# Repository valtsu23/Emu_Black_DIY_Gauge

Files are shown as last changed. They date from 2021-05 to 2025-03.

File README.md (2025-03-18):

# Emu_Black_DIY_Gauge
### Adafruit Feather M4 CAN Express with 2.4" TFT FeatherWing displaying sensor values 
### Updated 18.3.2025 and now supports Circuitpython 9 
Project goal was to create a small gauge for my Honda S2000 that displays time and sensor values from car ECU. 
Car is equipped with Ecumaster Emu Black ECU that can send data to CAN bus. Power supply for the device is 12v. 

### Hardware: 
- Adafruit Feather M4 CAN Express with ATSAME51 
- Adafruit 2.4" TFT FeatherWing 
- Adafruit DS3231 Precision RTC Breakout 
- JST-SM 4pin connector
- 5v regulator circuit
  - 7805 regulator
  - 1uF 35v tantalum capacitor
  - Proto board pcb
 
### Case
- Original desing (feather-tft-case): https://www.thingiverse.com/thing:2209964/files
- I removed the hole for the switch and added hole for the connector
- 3d printed from PETG
- 4 x M2.5 Machine Screws

### Cost
- Parts in total about 80€ 
- Case was 20€ printed by a hobbyist

### Display features: 
- 3 different tabs showing different values and the tab can be changed by touching the screen
- Last used tab is saved to SD card and read from there on boot 
- Video of the working display: https://youtu.be/Mr_nFbw4OqU

### Wiring notices
- DS3231 VIN to Feather 3V pin
- Capacitor on input side of the regulator 
- Regulator output connected to USB-pin on Feather (not the recommended way, because it might damage the computer plugged to usb-port)
More info: https://learn.adafruit.com/adafruit-feather-m0-basic-proto/power-management

### Understanding how it works
- The code.py file contains the main code. I have used many examples to build the code.
- Data showed on the diplay is split in several goups. There is one main group and 5 lower groups. Data of the 4 groups is changed during the tab change. 
Check links 1 and 2 about controlling the display. 
- Link 3 helps you undestand the Can-Bus communication. 
- I'm using Struct library to unpack the Can-Bus messages (links 4 and 5)

### Useful links
1. https://learn.adafruit.com/adafruit-2-4-tft-touch-screen-featherwing/2-4-tft-featherwing
2. https://learn.adafruit.com/circuitpython-display-support-using-displayio/library-overview
3. https://learn.adafruit.com/using-canio-circuitpython
4. https://docs.python.org/3/library/struct.html
5. https://en.wikipedia.org/wiki/C_data_types

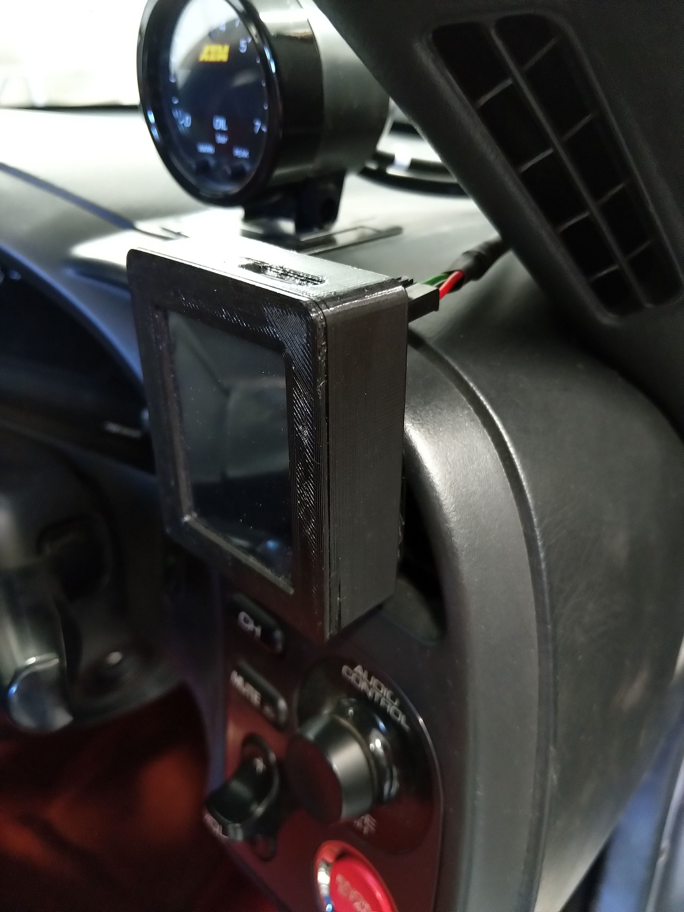
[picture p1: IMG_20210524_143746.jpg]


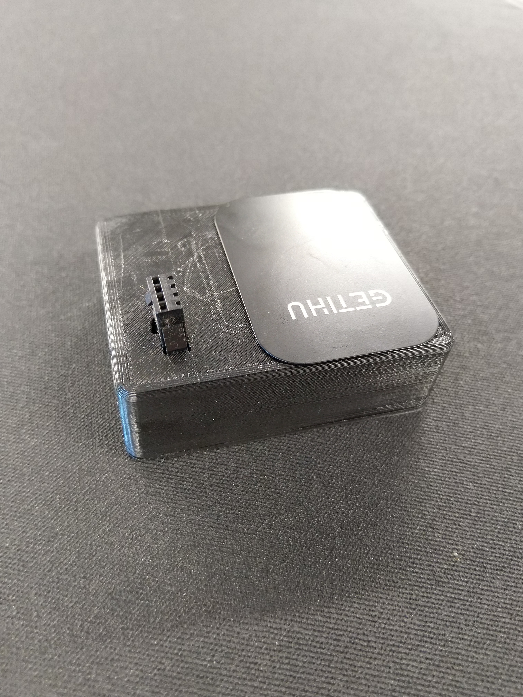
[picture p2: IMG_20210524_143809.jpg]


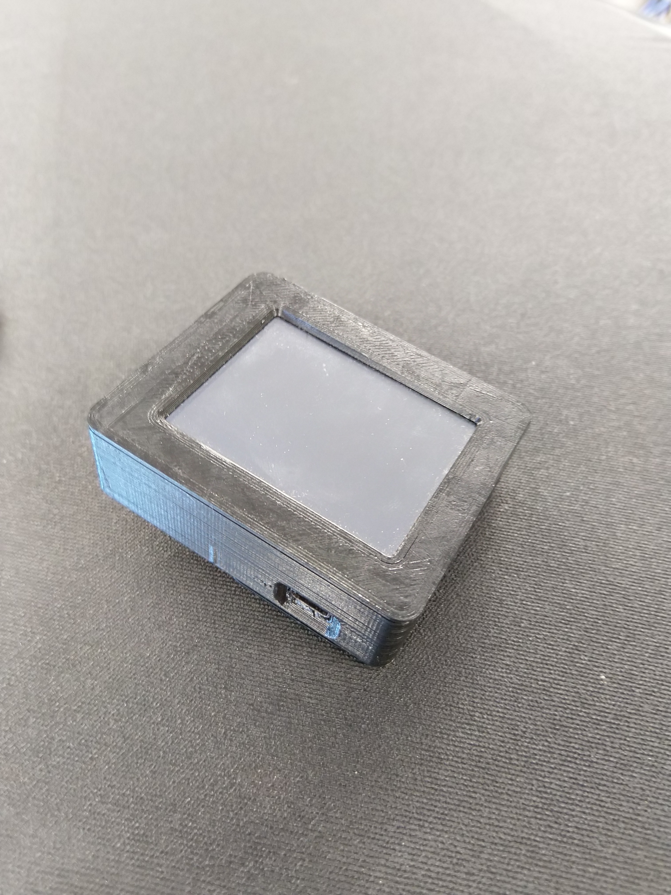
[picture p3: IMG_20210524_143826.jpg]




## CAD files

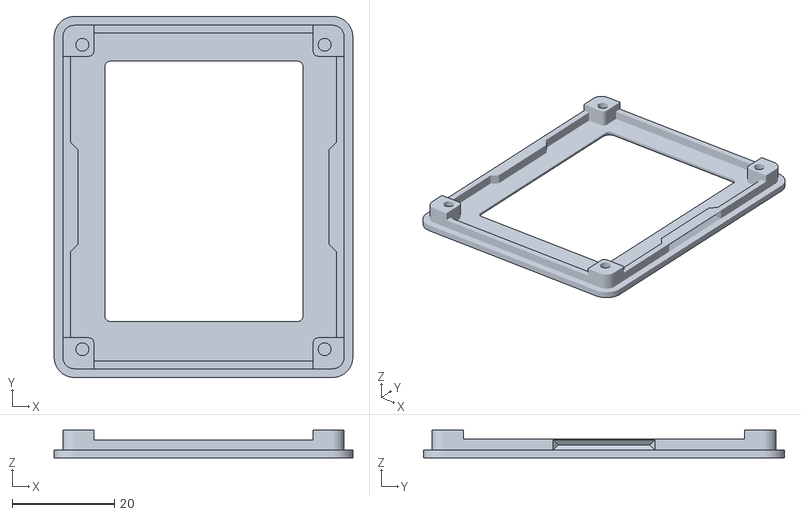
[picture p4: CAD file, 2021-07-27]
Case/TFT top.stl
58.6 x 70.8 x 5.40

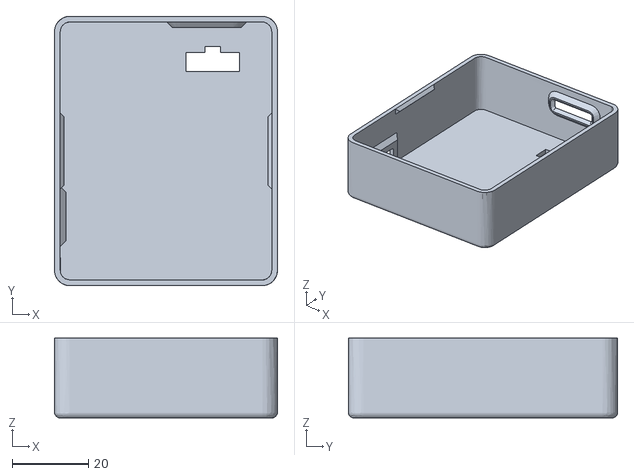
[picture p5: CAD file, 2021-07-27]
Case/TFT case V2.stl
58.6 x 70.8 x 21.0

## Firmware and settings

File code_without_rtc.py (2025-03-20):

# Version 3.0
# Circuitpython 9 support
# Added SD card check, error handling and SD card error message
# Other small improvements

import board
import busio
import struct
import time
import displayio
import digitalio
import canio
import fourwire
from adafruit_display_text import label
from adafruit_bitmap_font import bitmap_font
import adafruit_ili9341
import adafruit_stmpe610
import adafruit_ds3231
import adafruit_sdcard
import storage

# SPI communication pins
spi = board.SPI()

# SD card
sd_cs = digitalio.DigitalInOut(board.D5)
# Error handling if SD card not working
sd_card_ok = 1
try:
    sdcard = adafruit_sdcard.SDCard(spi, sd_cs)
except OSError:
    sd_card_ok = 0
    tab_now = 1
# If sd card is ok, mount it
if sd_card_ok == 1:
    vfs = storage.VfsFat(sdcard)
    storage.mount(vfs, "/sd")

if False:   # change to True if you want to write the time!
    #                     year, mon, date, hour, min, sec, wday, yday, isdst
    t = time.struct_time((2021,  3,   16,   10,  30,  00,    0,   -1,    -1))
    # you must set year, mon, date, hour, min, sec and weekday
    # yearday is not supported, isdst can be set but
    # we don't do anything with it at this time

    print("Setting time to:", t)     # uncomment for debugging
    rtc.datetime = t
    print()

# Create library object using our Bus SPI port
displayio.release_displays()

# TFT pins
tft_cs = board.D9
tft_dc = board.D10

display_bus = fourwire.FourWire(spi, command=tft_dc, chip_select=tft_cs)
display = adafruit_ili9341.ILI9341(display_bus, width=240, height=320, rotation=90)

# Touch
st_cs_pin = digitalio.DigitalInOut(board.D6)
st = adafruit_stmpe610.Adafruit_STMPE610_SPI(spi, st_cs_pin)

# For registering just one touch
touched = 0

# Groups
error_group = displayio.Group(x=0, y=0)
tab_number_group = displayio.Group(x=0, y=0)
row1_group = displayio.Group(x=0, y=0)
row2_group = displayio.Group(x=0, y=108)
row3_group = displayio.Group(x=0, y=214)
lines_group = displayio.Group(x=0, y=0)

# Display group
view = displayio.Group()
display.root_group = view
view.append(error_group)
view.append(lines_group)
view.append(tab_number_group)
view.append(row1_group)
view.append(row2_group)
view.append(row3_group)


# Colors
line_color = 0xFFFFFF
data_color = 0xFFFFFF
error_color = 0xFF0000

# Lines
line_bitmap = displayio.Bitmap(240, 2, 1)
line_palette = displayio.Palette(1)
line_palette[0] = line_color
line_1 = displayio.TileGrid(line_bitmap, pixel_shader=line_palette, x=0, y=106)
line_2 = displayio.TileGrid(line_bitmap, pixel_shader=line_palette, x=0, y=212)
# Draw the lines
lines_group.append(line_1)
lines_group.append(line_2)

# Default Label styling:
TABS_X = 0
TABS_Y = 0

# Fonts
fontB = bitmap_font.load_font("/Helvetica-Bold-62.bdf")
fontS = bitmap_font.load_font("/Helvetica-Bold-35.bdf")
fontVS = bitmap_font.load_font("/Helvetica-Bold-21.bdf")

# Error messages (Only SD card error in use)
error_label = label.Label(fontVS, text="SD ERROR", color=error_color, scale=1)
error_label.x = TABS_X + 130
error_label.y = TABS_Y + 10
if sd_card_ok == 0:
    error_group.append(error_label)

# Tab number
tab_number_label = label.Label(fontVS, text="0", color=data_color, scale=1)
tab_number_label.x = TABS_X + 5
tab_number_label.y = TABS_Y + 10
tab_number_group.append(tab_number_label)

# Data rows
# Item 1
# Coolant temp
cltt_label = label.Label(fontS, text="CLT", color=data_color, scale=1)
cltt_label.x = TABS_X + 10
cltt_label.y = TABS_Y + 50

# Coolant temp label objects
clt_label = label.Label(fontB, text="NA", color=data_color, scale=1)
clt_label.x = TABS_X + 105
clt_label.y = TABS_Y + 50

# Item 2
# Lambda text label objects
lambdat_label = label.Label(
    fontVS, text="Lambda", color=data_color, scale=1)
lambdat_label.x = TABS_X + 10
lambdat_label.y = TABS_Y + 50

# Lambda label objects
lambda_label = label.Label(fontB, text="NA", color=data_color, scale=1)
lambda_label.x = TABS_X + 105
lambda_label.y = TABS_Y + 50

# Item 3
# Oil p. text label objects
oilpt_label = label.Label(fontS, text="Oil p.", color=0xFFFFFF, scale=1)
oilpt_label.x = TABS_X+10
oilpt_label.y = TABS_Y+50

# Oil pressure label objects
oilp_label = label.Label(fontB, text="NA", color=0xFFFFFF, scale=1)
oilp_label.x = TABS_X+105
oilp_label.y = TABS_Y+50

# Item 4
# Oil temperature text label objects
oiltt_label = label.Label(fontS, text="Oil t.", color=data_color, scale=1)
oiltt_label.x = TABS_X + 10
oiltt_label.y = TABS_Y + 50

# Oil temperature label objects
oilt_label = label.Label(fontB, text="NA", color=data_color, scale=1)
oilt_label.x = TABS_X + 105
oilt_label.y = TABS_Y + 50

# Item 5
# Intake air temperature text label objects
iatt_label = label.Label(fontS, text="IAT", color=data_color, scale=1)
iatt_label.x = TABS_X + 10
iatt_label.y = TABS_Y + 50

# Oil temperature label objects
iat_label = label.Label(fontB, text="NA", color=data_color, scale=1)
iat_label.x = TABS_X + 105
iat_label.y = TABS_Y + 50

# Rows
row1 = row1_group
row2 = row2_group
row3 = row3_group

def clear_row(row):
    for x in range(len(row)):
        row.pop()

def tab1():
    clear_row(row1)
    clear_row(row2)
    clear_row(row3)
    row1_group.append(lambdat_label)
    row1_group.append(lambda_label)
    row2_group.append(cltt_label)
    row2_group.append(clt_label)
    row3_group.append(oiltt_label)
    row3_group.append(oilt_label)

def tab2():
    clear_row(row1)
    clear_row(row2)
    clear_row(row3)
    row1_group.append(lambdat_label)
    row1_group.append(lambda_label)
    row2_group.append(oiltt_label)
    row2_group.append(oilt_label)
    row3_group.append(oilpt_label)
    row3_group.append(oilp_label)

def tab3():
    clear_row(row1)
    clear_row(row2)
    clear_row(row3)
    row1_group.append(lambdat_label)
    row1_group.append(lambda_label)
    row2_group.append(cltt_label)
    row2_group.append(clt_label)
    row3_group.append(iatt_label)
    row3_group.append(iat_label)

# Read last tab drom sd card in startup if sd card ok
if sd_card_ok == 1:
    tabfile = open("/sd/tab_memory.txt", "r")
    tab_now = int(tabfile.readline())
    tabfile.close()

# Save tab to sd card
def save_tab():
    tabfile = open("/sd/tab_memory.txt", "w")
    tabfile.write("%0.f\n" % tab_now)
    tabfile.close()

# Tab control
def change_tab():
    tab_number_group.pop()
    tab_number_label.text = str(tab_now)
    tab_number_group.append(tab_number_label)
    if tab_now == 1:
        tab1()
    if tab_now == 2:
        tab2()
    if tab_now == 3:
        tab3()
    if sd_card_ok == 1:
        save_tab()

# Run at startup
change_tab()

# CAN BUS
# The CAN transceiver has a standby pin, bring it out of standby mode
if hasattr(board, 'CAN_STANDBY'):
    standby = digitalio.DigitalInOut(board.CAN_STANDBY)
    standby.switch_to_output(False)

# The CAN transceiver is powered by a boost converter, turn on its supply
if hasattr(board, 'BOOST_ENABLE'):
    boost_enable = digitalio.DigitalInOut(board.BOOST_ENABLE)
    boost_enable.switch_to_output(True)

# Use this line if your board has dedicated CAN pins.
# (Feather M4 CAN and Feather STM32F405)
can = canio.CAN(rx=board.CAN_RX, tx=board.CAN_TX, baudrate=500_000, auto_restart=True)

# CAN listener 0x600 - 0x603
listener = can.listen(matches=[canio.Match(0x600, mask=0x604)], timeout=1)

# Needed for CAN BUS
old_bus_state = None

# Main loop
while True:
    # Touch control
    while st.touched:
        while not st.buffer_empty:
            ts = st.touches
            for point in ts:
                # Perform transformation to get into
                # display coordinate system! (Not in use)
                # y = point["y"]
                # x = 4096 - point["x"]
                # x = 2 * x // 30 - 18
                # y = 8 * y // 90 - 18
                # To register just one touch
                touched = 1
    if touched == 1:
        tab_now = tab_now + 1
        if tab_now == 4:
            tab_now = 1
        touched = 0
        change_tab()

    # CAN BUS
    # Bus state information
    bus_state = can.state
    if bus_state != old_bus_state:
        print(f"Bus state changed to {bus_state}")
        old_bus_state = bus_state
    message = listener.receive()

    # Message handling
    if message is None:
        print("No message received within timeout")
        # time.sleep(1)
        continue

    data = message.data
    if len(data) != 8:
        print(f"Unusual message length {len(data)}")
        # time.sleep(1)
        continue

    id = message.id
    if id == 0x600:
        # Unpack message
        message = struct.unpack("<HBbHH", data)
        # Just for debugging
        # print(f"0x600: {message}")
        # Update intake air temperature
        iat_label.text = str(message[2])
    if id == 0x602:
        message = struct.unpack("<HBBBBh", data)
        oilt_label.text = str(message[2])
        oil_p = message[3]*0.0625
        oilp_label.text = str(round(oil_p, 1))
        clt_label.text = str(message[5])
    if id == 0x603:
        message = struct.unpack("<bBBBHH", data)
        lambda_value = message[2]*0.0078125
        lambda_label.text = str(round(lambda_value, 2))

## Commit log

2021-07-27 Add files via upload
    Case files for 3d printer
    [TFT case V2.stl, TFT top.stl]
2022-07-25 Version 2.0
    # Added SD card check, error handling and SD card error message
    # Other small improvements
    [code.py]
